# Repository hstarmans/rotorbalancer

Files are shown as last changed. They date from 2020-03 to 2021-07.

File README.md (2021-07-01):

# Rotor balancer
The rotor balancer can be used to balance propellers from flying drones or laser mirror motors.
The instrument is also a tachometer and can record the speed of rotors.
The Nano 33 BLE pulses the motor via hardware pwm and records the accelerometer signal via the onboard LSM9DS1 accelerometer chip.
During rotation the signal of a [TCRT5000 IR LED](https://opencircuit.nl/Product/TCRT5000-Infrarood-lijn-detectie-module) is read out to detect the position of the rotor.
The amplitude of the accelerometer signal is proportional to the unbalanced mass. The phase difference between the infrared LED and the accelerometer indicates the position where a balance weight, aka. putty, has to be placed.
In the case of two plane unbalance, the phase difference between the IR Led and the accelerometer can be dependent upon rotor speed.  
So far, I have only used the single-plane 2 run method to balance the rotor. Multi-plane balancing is not implemented.  
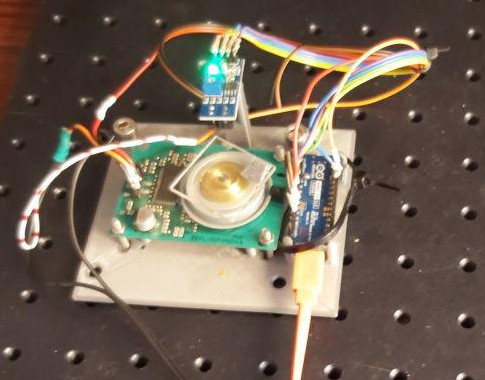
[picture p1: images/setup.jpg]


# Installation
Compile the firmware with Platform IO, a plugin for VSCode, and upload it to the Arduino Nano 33 BLE.
Connect to the board with a baudrate of 115200. Five options are available; start samples, calibrate IR sensor, spin polygon,
check pulse frequency and set pulse frequency.  
Place an aluminum foil sticker on your rotor. Ensure the infrared sensor detects the sticker and set the threshold using a screwdriver on the TCRT5000 IR LED sensor so it only changes when it detects the sticker. Use other menus to check if the polygon is spinning and set the pulse rate. 
Menus can typically be exited by pressing the 1 key and sending it with enter.
A program to collect measurements is available for python.  
The python program is installed as follows, install requirements;
```console
pip install -r requirements.txt
```
Install package;
```console
pip install -e .
```
Program is run as follows;
```console
python main.py --plot --frequency 20 --filename '20hertz.p'
```
An alternative is to run it via the python interpreter;
```python
from rotorbalancer import tools
tools.runtest(10,11,1,'test')
```
Example measurements can found in the measurements folder. 

# Video
I made a video of the setup for a better impression.  
[](https://youtu.be/xFNtZbOfEfQ)

# Measurements
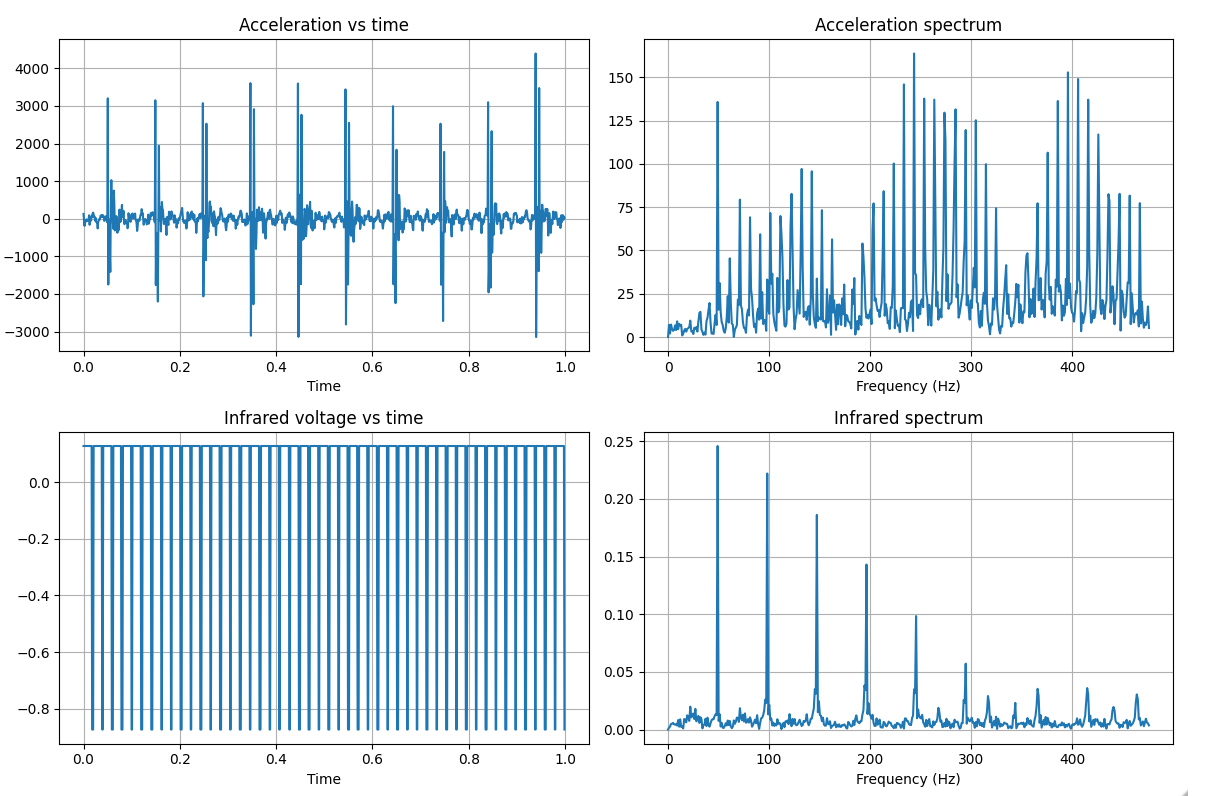
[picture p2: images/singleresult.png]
<br>
For each measurement, the rotor is pulsed at a certain frequency for 20 seconds to spin it up.
The motor is kept on and the acceleration and infrared signal are measured for 1 second.
Sampling is equidistant at 952 Hertz as this was the maximum sampling frequency of the accelerometer.
In single plane balancing it is assumed that the angle of the force is not dependent upon speed.
The phase-difference between the ir sensor and the acceloremeter determines the location where putty needs to be applied. 
The frequency and amplitude are determined via a Fourier transform. Using a peak detection algorithm, the first peak is selected.
Results are repeatable and standard deviation is in the range of 10-3 percent. Results are shown in the notebook folder. 
A balance weight of 0.060 gram [Weicon resin putty](https://www.weicon.de/en/products/adhesives-and-sealants/2-component-adhesives-and-sealants/epoxy-resin-systems/plastic-metal/298/epoxy-resin-putty) is applied. I used an AG204 Delta range from Mettler to measure the weight of the putty accurately.
As a lower cost alternative, pieces of aluminium tape could be used, as there is a direct relation between mass and surface area.
A small piece of aluminum tape is applied to trigger the IR Led sensor.  
Futher literature can be found in [Science direct](https://www.sciencedirect.com/science/article/pii/S2351988616300185) and at the site of [National Instruments](https://forums.ni.com/t5/Example-Programs/Two-Plane-Balancing-Example-with-DAQmx/ta-p/3996066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).
The measurements are available in the measurements folder. 

# Implementation details
I had to remove modemmanager as this caused problems with [arduino](https://forum.arduino.cc/index.php?topic=575194.0).
```console
sudo apt --purge remove modemmanager
```
The accelerometer libary from [Sparkfun](https://github.com/sparkfun/SparkFun_LSM9DS1_Arduino_Library) is used in a slightly modified form.

# BOM
Prism:  
4 sides, 30x30x2 mm  
Mirror motor:  
Panasonic AN44000A, other moters require different pins to be pulsed.
Mirror motors have 5 pins; PWM, MOTOR_EN, GND, Voltage and LCK_PIN.
PWM is speed control. Relation is not linear for all motors. GND is ground. Voltage is the supply voltage, ideally 24V. LCK_pin is
false if encoder and signal are not in sync. I cannot confirm the function of LCK_pin and MOTOR_EN. 
Changing them or looking at their input does not reveal any activity.
They are fixed for now to guarantee repeatability.

Accelerometer:  
The accelerometer of the LSM9DS1 is used, as it available on the Arduino Nano 33.  
IR sensor:  
The TCRT5000 IR LED sensor see [DIY LP turntable](https://www.stockholmviews.com/wp/diy-lp-turntable-tachometer/). I bought one [here](https://opencircuit.nl/Product/TCRT5000-Infrarood-lijn-detectie-module)  
Balancing putty:  
In the industry two systems are used. A 2 component epoxy resin putty by [Weicon](https://www.weicon.de/en/products/adhesives-and-sealants/2-component-adhesives-and-sealants/epoxy-resin-systems/plastic-metal/298/epoxy-resin-putty)
A single component UV curable expory resin system, e.g. by [Shenk](http://www.schenck-worldwide.com/PDF/de-de1/Epoxidharz-Unwucht-Korrektursystem.pdf). In german it is called Wuchtkitt. The compound has a ceramic filling and the density is 2 gram per cubic centimer. Component was ordered via [modular](https://www.modulor.de). The kitt becomes green upon mixing. After several hours it becomes very hard and can no longer be removed from prism.  
An alternative is to use lead or metal tape. Lead has a density of 11 gram per cubic centimer.  
Optical plate:  
Used an optical aluminum breadboard from Thorlabs with M6 screws as base. Do not attach the device to something heavy this make the measurements worse. Typically, you want it decoupled from the external world and place the object under study on foam or hang it on cords. During measurements, the prism was suspended in air with strings.

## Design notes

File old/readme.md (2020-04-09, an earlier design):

# Tests

First tests were done with a Raspberry Pi and an accerelometer.

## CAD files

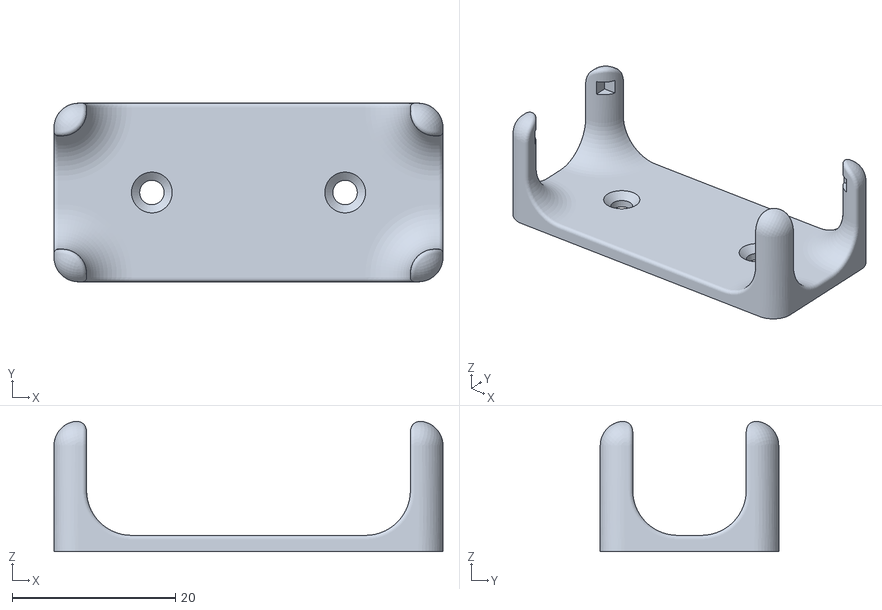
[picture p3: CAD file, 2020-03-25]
caddesigns/Arduino_Nano_Holder/files/Arduino_Nano_Holder_with_Mounting_Holes.stl
47.7 x 21.9 x 16.0

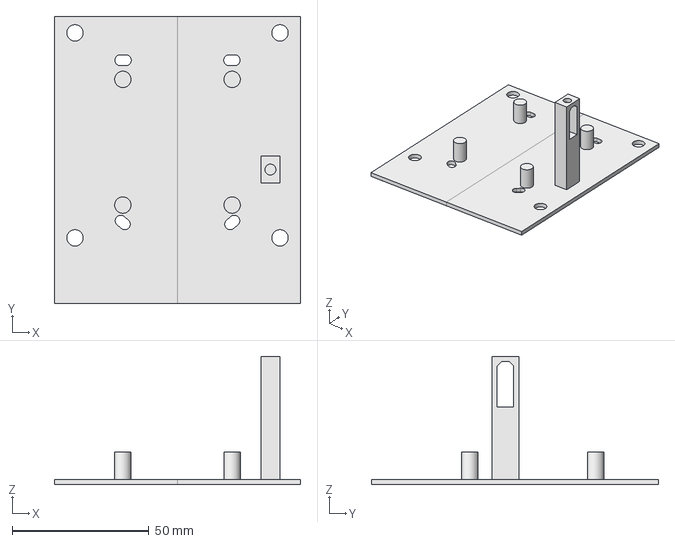
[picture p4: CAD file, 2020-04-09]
caddesigns/stabilizer.FCStd
90.0 x 105.0 x 47.0 mm

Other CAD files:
caddesigns/Arduino_Nano_Holder/files/Arduino_Nano_Holder.stl

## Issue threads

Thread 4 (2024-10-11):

Wrong rotation frequency calculation

ToGoOrNotToGo, 2024-10-11:
Hi,
thanks for this interesting project! I found a bug when using frequency resolutions other than 1 Hz. In calc.py rotfreq_and_force the inner get_first_peak function returns the index of the first peak instead of the frequency of that index:
`return peaks[0]+1, sign[peaks[0]]`
should be:
`return peaks[0] * df, sign[peaks[0]]`

regards
Tobias

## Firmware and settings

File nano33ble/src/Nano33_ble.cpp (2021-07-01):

/* Author: Rik Starmans
   Organization: Hexastorm
   License: GPL3
   About: polygon is pulsed for PANASONIC (AN44000A chip) scheme, midle pin, pin 3 AKA enable pin
          polygon is rotated and accelerometer data and IR
          sensor data is collected
*/

#include <Wire.h>
#include <SPI.h>
// modified fork
#include <SparkFunLSM9DS1.h>
#include "nrf.h"


// rotor pulsed via pin A3, i.e. pin 0.29 on microcontroller
#define PWM_PIN 29UL
// not sure about LCK and EN pin, they should be kept fixed!
#define LCK_PIN A2
#define EN_PIN A1
#define irsensorAPin A6
#define irsensorDPin 2


// Settings
const int startup_time = 20;  // seconds
const int samples = 952;
// pulse frequency != rotor frequency
// 20 hz approx 100 hz for panasonic
// WARNING: if frequency too small COUNTERTOP out of range!!
int frequency = 20;    // Hertz 


LSM9DS1 imu;
// TODO: move sample_freqs to LSM9DS1 class
const int sample_freqs[6] = {10, 50, 119, 238, 476, 952};

unsigned int sample_freq;
uint8_t ir_data[samples];
int16_t accel_data[samples];
// used for duty cycle, must be global
uint16_t buf[1]; 

void motoron(bool on){
  digitalWrite(EN_PIN, on);
  digitalWrite(LCK_PIN, on);
  NRF_PWM0->ENABLE = (int) on;
  NRF_PWM0->TASKS_SEQSTART[0] = (int) on;
}


void setuppolygon(int frequency) {
  const int counterclock = 125000;
  // counter top must be between 3..32767
  const uint16_t countertop = counterclock/frequency;
  const uint16_t dutycycle = countertop/2;
  buf[0] = {dutycycle};
  // sets up hardware pwm
  //  source https://github.com/andenore/NordicSnippets/blob/master/examples/pwm/main.c
  // Start accurate HFCLK (XOSC)
  NRF_CLOCK->TASKS_HFCLKSTART = 1;
  while (NRF_CLOCK->EVENTS_HFCLKSTARTED == 0) ;
  NRF_CLOCK->EVENTS_HFCLKSTARTED = 0;
  // Configure PWM_PIN as output, and set it to 0
  NRF_GPIO->DIRSET = (1 << PWM_PIN);
  NRF_GPIO->OUTCLR = (1 << PWM_PIN);
  NRF_PWM0->PRESCALER   = PWM_PRESCALER_PRESCALER_DIV_128; // 125kHz clock, see manual
  NRF_PWM0->PSEL.OUT[0] = PWM_PIN;
  NRF_PWM0->MODE        = (PWM_MODE_UPDOWN_Up << PWM_MODE_UPDOWN_Pos);
  NRF_PWM0->DECODER     = (PWM_DECODER_LOAD_Common       << PWM_DECODER_LOAD_Pos) | 
                          (PWM_DECODER_MODE_RefreshCount << PWM_DECODER_MODE_Pos);
  NRF_PWM0->LOOP        = (PWM_LOOP_CNT_Disabled << PWM_LOOP_CNT_Pos);
  NRF_PWM0->COUNTERTOP = (countertop << PWM_COUNTERTOP_COUNTERTOP_Pos);
  NRF_PWM0->SEQ[0].CNT = ((sizeof(buf) / sizeof(uint16_t)) << PWM_SEQ_CNT_CNT_Pos);
  NRF_PWM0->SEQ[0].ENDDELAY = 0;
  NRF_PWM0->SEQ[0].PTR = ((uint32_t)&buf[0]<< PWM_SEQ_PTR_PTR_Pos);
  NRF_PWM0->SEQ[0].REFRESH = 0;
  NRF_PWM0->SHORTS = 0;
  motoron(false);
}


void setup() {
  setuppolygon(frequency);
  pinMode(A3, INPUT);
  pinMode(LCK_PIN, OUTPUT);
  pinMode(EN_PIN, OUTPUT);
  pinMode(irsensorDPin, INPUT);
  pinMode(irsensorAPin, INPUT);
  Serial.begin(115200);
  while (!Serial);
  Wire1.begin();
  Wire1.setClock(400000);
  while (!imu.begin(0x6B, 0X1E, Wire1)) {
    Serial.println("Failed to communicate with LSM9DS1.");
    Serial.println("Will retry in 1 second.");
    delay(1000);
  }
  sample_freq = sample_freqs[imu.settings.accel.sampleRate-1];
  imu.calibrate();
}


void loop() {
    Serial.println("Press 1 to start samples.");
    Serial.println("Press 2 to calibrate IR sensor.");
    Serial.println("Press 3 to spin polygon.");
    Serial.println("Press 4 to check pulse frequency.");
    Serial.println("Press 5 to set pulse frequency.");
    Serial.setTimeout(2000);
    int int_received = Serial.parseInt();
    switch(int_received) {
      // parseInt polls and returns 0 if nothing is received so ignored
      case 0 : 
      break;
      case 1 : {
        Serial.setTimeout(500);
        motoron(true);
        Serial.print("Process time ");
        Serial.print(round(startup_time+samples/sample_freq));
        Serial.println(" seconds.");
        // wait for polygon to stabilize
        unsigned int iteration = 0;
        int tijd = millis();
        //TODO: you could simplify with sleep
        //      move the check after samples
        while(iteration < startup_time*sample_freq){
             if (imu.accelAvailable())
                {
                imu.readAccel();
                iteration = iteration + 1;
                }
        }
        int verschil = millis()-tijd;
        if(1.1*verschil<startup_time*1000||startup_time*1000<0.9*verschil){
          // frequency accelerometer is probably wrong
          Serial.println("Error: time difference out of bounds");
        }
        // execute measurements
        iteration = 0;
        int digitalout = 1;
        while(iteration<samples){
          if(digitalRead(irsensorDPin) == 0) digitalout = 0;
          if (imu.accelAvailable()){
            //ir_data[iteration] = analogRead(irsensorAPin);
            ir_data[iteration] = digitalout;
            imu.readAccel();
            accel_data[iteration] = imu.ax;
            digitalout = 1;
            ++iteration;
          }
        }
        // motor turned off after measurements
        motoron(false);
        Serial.print("Pulse frequency ");
        Serial.print(frequency);
        Serial.println(" Hz.");
        Serial.print("Sample frequency ");
        Serial.print(sample_freq);
        Serial.println(" Hz.");
        Serial.print("Samples collected ");
        Serial.println(samples);
        for(int sample = 0; sample<samples; sample++){
          Serial.println(ir_data[sample]);
          Serial.println(accel_data[sample]);
        }
        Serial.println("Measurement completed");
      }
        break;
      case 2 :
        Serial.setTimeout(500);
        Serial.println("Starting IR calibration, press 1 to exit.");
        while(true)
        {
          if (Serial.parseInt() == 1) break;
          Serial.println(analogRead(irsensorAPin));
          Serial.println(digitalRead(irsensorDPin));
        }
        break;
      case 3 :
        motoron(true);
        while(true){
          Serial.setTimeout(500);
          Serial.println("Spinning polygon, press 1 to exit.");
          if (Serial.parseInt() == 1){
            motoron(false);
            break;
          }
        }
        break; 
      case 4 :{
        Serial.setTimeout(1000);
        Serial.println("Measuring pulse frequency.");
        motoron(true);
        int old = 0;
        int counter = 0;
        int current = 1;
        float tijd = millis();
        while (counter<100)
        {
         current = digitalRead(A3);
         if((current==1)&&(old==0)) counter += 1;
         old = current;
        }
        float frequency = (float)counter/((millis()-tijd)/1000);
        Serial.print(frequency);
        Serial.println(" Hz");
        Serial.println("Pulse test completed.");
        motoron(false); 
        break;
        }
      case 5 :
        while (true){
          Serial.setTimeout(1000);
          frequency = Serial.parseInt();
          Serial.println("Set pulse frequency in Hz.");
          if (frequency>4){
            Serial.println("Accepted.");
            setuppolygon(frequency);
            break;
          }
          else if(0<frequency && frequency<4){
            Serial.println("Invalid, countertop will overflow.");
          }
          // ignore 0, default return value of parseInt
        }
        break;
      default:
        Serial.println(int_received); 
        Serial.println("Invalid command");
        break;
    };
}

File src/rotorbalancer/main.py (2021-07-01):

# Author: Rik Starmans
# Date: 18-3-2020
# Description: program to upload arduino code and plot results
from subprocess import run
from time import sleep
import serial
import serial.tools.list_ports
import argparse
import pickle

from . import calc

# Placer holder for the Pyserial connection to the Nano33ble
# set by getserial
SER = None


def upload(filename='Nano33_ble/Nano33_ble.ino'):
    '''upload firmware to the board via the arduino commmand line interface

    Documentation details of arduino command line can be found at
    https://github.com/arduino/Arduino/blob/master/build/shared/manpage.adoc
    Program can also be configured by running the IDE.

    Keyword arguments:
    filename -- location of file to upload
    '''
    cmd = ['arduino', '--upload', '--port', getports()[0], filename]
    arduino = run(cmd)
    if arduino.returncode:
        raise Exception("Exit code not zero, operation failed")
    sleep(3)  # wait for board to boot


def test_received(text):
    '''check of text is received on serial port

    Keyword arguments:
    text -- text as string expected to be received on serial line

    Returns:
    The full line of text this keyword was in as string
    '''
    received, iteration = '', 0
    ser = getserial()
    while text not in received:
        received, iteration = ser.readline().decode().strip(), iteration+1
        if iteration > 15:
            print("Received {}".format(received))
            raise Exception('Did not receive text; "{}"'.format(text))
    return received


def getports(name='COM5'):  # Nano 33 BLE on raspberry
    '''get serial port for the NANO 33 BLE

    name -- specifier of device.. can differ for e.g. be COM5 or Nano 33 BLE

    Returns:
    List with ports which have a Nano 33 BLE attached
    '''
    arduino_ports = [p.device for p in serial.tools.list_ports.comports()
                     if name in p.description]
    if not len(arduino_ports):
        raise Exception("Arduino Nano 33 BLE not detected")
    return arduino_ports


def getserial():
    '''get serial object for the NANO 33 BLE

    The result is also set as global as a serial object.
    Closing and opening the port too many
    times can break connection with the board.
    This prevents it from being opened to many times.

    Returns
    pyserial object
    '''
    global SER
    if not SER:
        SER = serial.Serial(getports()[0], 115200, timeout=1)
    return SER


def set_frequency(frequency):
    '''set the hardware pwm frequency of the Nano 33BLE

    The frequency of the oscillator is use to move the motor.

    Keyword arguments:
    frequency -- frequency of the oscillitor in Hz
    '''
    if frequency < 5:
        raise Exception("Out of range, change clock divider in firmware")
    ser = getserial()
    test_received('Press 5 to set pulse frequency.')
    ser.write('5'.encode())
    test_received('Set pulse frequency')
    ser.write(str(frequency).encode())
    test_received('Accepted.')


def main(frequency=20, plot=False, upload=False):
    """collects samples from the client

    Keyword arguments:
    upload -- if true firmware is recompiled and uploaded to the board
    plot -- if true acceleromater an infrared signal are plotted vs time
            the amplitude of their Fourier transform is also shown
    frequency -- frequency used of the oscillator in Hertz

    Returns:
    Python dictionary with keys;
        ac_meas -- accelerometer measurements as list
        ir_meas -- infrared measurements as list
        purse_freq -- the frequency at which the rotor was driven
        sample frequency -- sample frequency of the signal typically 952 Hz
    """
    ser = getserial()
    # read all lines to clear buffer
    ser.readlines()
    print("Setting frequency to {} Hz".format(frequency))
    set_frequency(frequency)
    if upload:
        upload()
    test_received('Press 1 to start samples.')
    ser.write('1'.encode())
    received = test_received('Process time')
    measurement_time = float(received.split(' ')[2])
    print("Waiting {} seconds for operation" +
          " to complete".format(measurement_time))
    slept = 0
    sleep_step = 5  # seconds
    while slept < measurement_time:
        slept += sleep_step
        if slept > measurement_time:
            sleep(measurement_time-slept+sleep_step)
            slept = measurement_time
        else:
            sleep(sleep_step)
        print(" Completed {:.2f} %".format(slept/measurement_time*100))
    received = test_received('Pulse frequency')
    rotor_frequency = int(received.split(' ')[2])
    print("Pulse frequency {} Hz".format(rotor_frequency))
    received = test_received('Sample frequency')
    sample_frequency = int(received.split(' ')[2])
    print("Sample frequency {} Hz".format(sample_frequency))
    received = test_received('Samples collected')
    samples = int(received.split(' ')[2])
    print("Samples collected {}".format(samples))
    ac_meas, ir_meas = [], []
    for sample in range(samples*2):  # you receive accelerometer and ir
        res = int(ser.readline().decode().strip())
        ac_meas.append(res) if sample % 2 else ir_meas.append(res)
    results = {'ac_meas': ac_meas,
               'ir_meas': ir_meas,
               'puls_freq': rotor_frequency,
               'sample_freq': sample_frequency}
    test_received('Measurement completed')
    sleep(1)
    print(calc.rotfreq_and_force(results))
    if plot:
        calc.plotdata(results)
    return results


def parser():
    '''creates parser for the command line interface of this script

    Returns:
    Argument parses
    '''
    parser = argparse.ArgumentParser(add_help=True)
    parser.add_argument('--plot',
                        action="store_true",
                        default=False, help='Plot results')
    parser.add_argument('--upload',
                        action="store_true",
                        default=False, help='Upload firmware')
    parser.add_argument('--frequency',
                        action="store",
                        default=20,
                        type=int,
                        help='Set frequency in Hz')
    parser.add_argument('--filename',
                        action="store",
                        default=None,
                        type=str,
                        help='Filename to store results with pickle.')
    return parser


if __name__ == "__main__":
    parser = parser()
    args = parser.parse_args()
    results = main(args.frequency, args.plot, args.upload)
    if args.filename:
        pickle.dump(results,
                    open(args.filename, 'wb'))

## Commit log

2019-09-24 added BOM
    added bom with accelerometer
2020-01-04 added brief test for MMA8452Q
    tested succesfully on raspberry pi
2020-01-10 did succesfull test with accelerometer
    determined cross correlation with artificial signal.
    was able to determine the RPM with a photo tachometer
2020-01-24 added arduino nano 33 and result experiments
2020-01-27 added holder for trct5000 led
    [stabilizer.FCStd]
2020-02-02 added link to make arduino ide work
2020-02-08 added arduino 33 ble sketch
    [stabilizer.FCStd]
2020-02-11 still need to increase hertz magnetometer
2020-02-27 added improved accelerometer library
2020-03-18 added python client script script can be used to receive samples not tested
2020-03-18 added python client
    can be used to readout arduino code, untested
2020-03-21 added hardware pwm example
2020-03-22 added hardware pwm and tested software for Nano33
2020-03-22 client finished
    python client is working.
    Sleeping of rotor still seems incorrect.
2020-03-25 added designs of baseplate and arduino nanoholder
    [Arduino_Nano_Holder.stl, Arduino_Nano_Holder_with_Mounting_Holes.stl, stabilizer.FCStd]
2020-03-26 added method calibrate IR sensor
2020-03-30 fixed phase difference
    still need to do trials with test weight
    [client.py, plotresults.py]
2020-04-04 added digtal pin read out
    instead of a sample at one timepoint, a sample over
    the entire segment is taken.
    This simplifies interpertation of the results and
    seems to make the readings more accurate.
2020-04-09 added requirements, fixed small bug with new numpy
    [calc.py]
2020-04-09 improved cad design, removed sketch bugs and increased offset diode
    [stabilizer.FCStd]
2020-04-09 added optical plate
2020-04-09 added autodetect, fixed 2 bugs
    [calc.py, main.py]
2021-06-29 fixed rotorbalancer layout
2021-06-30 rotor should be fixed
    [Nano33_ble.cpp, calc.py, main.py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]
2021-07-01 added current interpretation of pins
